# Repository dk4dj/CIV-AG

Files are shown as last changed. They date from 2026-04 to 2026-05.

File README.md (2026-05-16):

# WT32-ETH01 — CI-V → Antenna Genius Bridge

Arduino sketch for the **WT32-ETH01** (ESP32 + LAN8720). Reads Icom CI-V frequency and TX status, automatically switches a **4O3A Antenna Genius** antenna selector, and provides reliable TX inhibit for both the Icom transceiver and SmartSDR/FlexRadio via a two-layer interlock implementation. An optional **EA DOGL128W-6** display with rotary encoder provides on-device status, antenna selection, and system information.

---

## Features

- **Automatic AG discovery** — UDP broadcast on port 9007; extracts IP, port, serial, firmware, ports, antennas, mode, uptime
- **Full AG configuration readout** — band table and antenna list on every connect
- **CI-V frequency tracking** on UART2 — transceiver address learned automatically; active polling (Cmd 0x03) after `CIV_BROADCAST_TIMEOUT_MS` (1 s)
- **CI-V TX status** (Cmd 0x1C/0x00) polled every 200 ms — drives TX/RX indicator on display and web UI
- **Automatic band → antenna mapping** based on AG TX masks
- **Four-layer TX protection** — all controlled together via `setConflict()`:
  - GPIO4 HIGH → hardware PTT inhibit line
  - CI-V Cmd 0x16/0x66 → TX Inhibit on newer Icom transceivers
  - FlexRadio server `state=PTT_REQUESTED` → AG sets `inhibit=1` on Port B
  - SmartSDR Ethernet Interlock `not_ready` → SmartSDR TX blocked directly
- **Conflict reason display** — web UI and log show which transceiver was inhibited with address, frequency and antenna name
- **Correct conflict detection** — `wantedAntId` tracks the last requested antenna independently of AG status (AG sets `txant=0` when `inhibit=1`); re-evaluated on every Port B update
- **Source=AUTO guard** — ignores AG startup state for own port until first CI-V frame received
- **CI-V timeout** (`CIV_TIMEOUT_MS` = 5 s) — releases port and activates all inhibit mechanisms
- **FlexRadio two-layer implementation:**
  - **Server** (port 4992, up to `FLEX_MAX_CLIENTS` = 4): emulates a FlexRadio for the AG; sends `PTT_REQUESTED` proactively after `keepalive enable`
  - **Client**: connects to real FLEX radio; `interlock create type=ANT model=... valid_antennas=`; `not_ready`/`ready` with hex interlock ID
- **Separate UDP sockets** — `flexDiscUdp` (send-only) and `flexListenUdp` (receive-only on port 4992) to avoid ESP32 conflict
- **Automatic FLEX radio selection** — priority: AG Port 2 nickname → NVS default IP → single radio → user selection
- **Persistent default radio** — NVS (`Preferences`), survives reboot
- **Shared JSON builder** `buildStatusJson()` — identical data for SSE push and `/api` polling
- **Band-ID lookup** by `bands[i].id` (AG Band-IDs are 1-based; array is 0-based)
- **Splash screen** at boot (128×64 px, PROGMEM)
- **Display inversion** on any conflict or CI-V timeout (ST7565 hardware invert)
- **Built-in web interface** on port 80 with live SSE, FLEX selection panel, conflict detail
- **Log export** — `GET /log`, 300 timestamped entries
- **Non-blocking architecture** throughout
- **DHCP** — no network configuration required

---

## Hardware

### GPIO Assignment

| Signal | GPIO | Notes |
|---|---|---|
| ETH CLK input | 0 | `ETH_CLOCK_GPIO0_IN`, from LAN8720 crystal |
| ETH Power/Reset | 16 | LAN8720 nRST — try `-1` if boot shows reset timeout |
| ETH MDC | 23 | |
| ETH MDIO | 18 | |
| ETH RMII (fixed) | 19, 21, 22, 25, 26, 27 | Cannot be reassigned |
| CI-V RX (UART2) | 5 | 1 kΩ pull-up to 3.3 V recommended |
| CI-V TX (UART2) | 17 | Active polling + TX Inhibit frames |
| TX inhibit / conflict output | 4 | HIGH = any conflict or CI-V timeout active |
| Display SI (MOSI) | 15 | Software-SPI |
| Display SCK | 14 | Software-SPI |
| Display CS | 12 | Active low |
| Display A0 | 2 | Strapping pin — safe after boot |
| Display RST | 33 | Active low |
| Encoder A | 39 | Input-only, ISR CHANGE, ext. 10 kΩ pull-up **required** |
| Encoder B | 36 | Input-only, ISR CHANGE, ext. 10 kΩ pull-up **required** |
| Encoder button | 35 | Input-only, polled, ext. 10 kΩ pull-up **required** |

> GPIO 35/36/39 are input-only with no internal pull-ups. GPIO 36/39 lie in register `GPIO.in1.val` (not `GPIO.in`). The ISR reads both pins as `(GPIO.in1.val >> (PIN - 32)) & 1`.

---

## Display & Encoder

### Menu states

| State | How to enter | How to leave |
|---|---|---|
| `MENU_STATUS` | Default / timeout | Short press → `MENU_ANT_SELECT`; long press ≥1s → `MENU_INFO` |
| `MENU_INFO` | Long press ≥1s from Status | Any press → `MENU_STATUS` |
| `MENU_ANT_SELECT` | Short press from Status or rotate | Press → `MENU_CONFIRM`; timeout |
| `MENU_CONFIRM` | Press from Ant Select | Press (confirm) or timeout |
| `MENU_FLEX_SELECT` | Automatic when multiple FLEX radios found | Short press = select; long press ≥2s = select + set NVS default |

### Status screen layout
```
21.465 MHz              RX     ← TX/RX indicator (inverted block when TX)
Band: 15m
Ant:  Beam_OB11-3
AG: OK  Port A           ← bottom status bar
```

### Info screen (long press)
```
WT32: 192.168.1.202
AG:   192.168.1.221
FW:4.1.8 S/N:C7-F6-42
FLEX: 192.168.1.100
      (Flexi)
────────────────────
CI-V: 0x94   19200 Bd
[Taste]=zurück
```

### Encoder: full 4-state Gray-code decoding
Both channels (GPIO 39/36) trigger `CHANGE` interrupts. The ISR uses a 4-bit state machine — only valid Gray-code transitions count; glitches and crosstalk are filtered automatically. Adjust `ENC_PULSES_PER_DETENT` (default 4) if steps are missed or doubled.

---

## Web Interface

Open `http://<device-ip>/` in any browser.

| Section | Content |
|---|---|
| Funkgerät (CI-V) | Address, frequency, active band, TX/RX status |
| Antenna Genius | Name, IP, firmware, uptime, status |
| Port-Belegung | Port A/B antenna/band, **Funkgerät TX** (from Cmd 0x1C), conflict badge with inhibited TRX details, FlexRadio status |
| FLEX-Radio-Auswahl | Yellow warning card when multiple radios found |
| Band-/Antennen-Konfiguration | Full AG tables |
| Debug-Log | Live SSE log, 300 entries, download |

**Endpoints:** `GET /`, `GET /api`, `GET /events`, `GET /log`, `POST /flex-select?ip=`, `POST /flex-default?ip=`

---

## CI-V Protocol Details

| Command | Direction | Purpose |
|---|---|---|
| `FE FE <trx> E0 03 FD` | WT32 → TRX | Poll frequency |
| `FE FE <trx> E0 00 FD` | TRX → WT32 | Frequency broadcast |
| `FE FE E0 <trx> 00 ... FD` | TRX → WT32 | Frequency response |
| `FE FE <trx> E0 1C 00 FD` | WT32 → TRX | Poll TX status (every 200 ms) |
| `FE FE E0 <trx> 1C 00 00 FD` | TRX → WT32 | RX status |
| `FE FE E0 <trx> 1C 00 01 FD` | TRX → WT32 | TX status |
| `FE FE <trx> E0 16 66 01 FD` | WT32 → TRX | TX Inhibit ON |
| `FE FE <trx> E0 16 66 00 FD` | WT32 → TRX | TX Inhibit OFF |

---

## FlexRadio Interlock

### Server (AG interlock)
- VITA-49 discovery broadcast every 2 s + TCP server port 4992
- Sends `S00000000|interlock state=PTT_REQUESTED` immediately after `keepalive enable`
- Log prefix: `[FLEX:N]`

### Client (SmartSDR direct interlock)
```
→ C1|client program CIV-Bridge
→ C2|interlock create type=ANT model=CIV-Bridge serial=DK4DJ-1 valid_antennas=
← R2|0|000000F4          ← hex interlock ID
→ C3|interlock not_ready 000000F4   ← conflict
→ C4|interlock ready 000000F4       ← resolved
```
- Log prefix: `[FRINT]`
- FLEX radio IP from `ip=` field in VITA-49 payload (more reliable than UDP sender IP)
- Auto-select priority: AG Port 2 nickname → NVS default → single radio → user

---

## TX Inhibit Mechanisms

All controlled via `setConflict(bool active, const char *reason)`:

| Layer | Mechanism | Effect |
|---|---|---|
| GPIO4 HIGH | `digitalWrite` | Hardware PTT line to TRX |
| CI-V 0x16/0x66 | Serial2 frame | Icom TX Inhibit (newer models) |
| FlexRadio server | `PTT_REQUESTED` status | AG `inhibit=1` on Port B |
| FlexRadio client | `interlock not_ready` | SmartSDR TX blocked directly |

`conflictReason` is built with CI-V address, frequency and antenna name. Set before `wantedAntId = 0` so the last active antenna appears in the conflict message.

---

## Antenna Conflict Detection

### wantedAntId

The AG sets `txant=0` in status messages when `inhibit=1`. Without a separate tracking variable `portTxAnt[AG_RADIO_PORT-1]` would become 0, causing false "no conflict" decisions.

`wantedAntId` is set in `setAGPort()`, cleared in `releaseAGPort()`, and never overwritten by AG status updates. `checkAndSignalConflict()` uses it as fallback when called with argument 0.

### Antenna menu filtering (`menuBuildAntList`)

The selection menu excludes:
- `activeAnt` — already active on own port
- `blockedAnt = portTxAnt[otherIdx]` — currently used by SmartSDR

This prevents selecting an antenna that is already occupied on either port.

---

## Setup

### Arduino IDE

| Setting | Value |
|---|---|
| Board | ESP32 Dev Module |
| Flash Mode | QIO |
| Flash Size | 4 MB |
| ESP32 core | Espressif ESP32 Arduino ≥ 2.x |

### Libraries

| Library | When required |
|---|---|
| ETH, WiFiUdp, WiFiClient, WiFiServer, WebServer, Preferences | Always (ESP32 core) |
| U8g2 by olikraus | `DISPLAY_ENABLED 1` |

### Key Configuration Constants

```cpp
#define DISPLAY_ENABLED          1
#define FLEX_EMULATION_ENABLED   1
#define AG_RADIO_PORT            1      // 1=Port A, 2=Port B
#define ETH_POWER_PIN            16     // try -1 on some board revisions
#define CONFLICT_PIN             4
#define CIV_BAUD                 19200
#define CIV_BROADCAST_TIMEOUT_MS 1000   // active poll after 1 s without broadcast
#define CIV_TIMEOUT_MS           5000   // release port after 5 s without CI-V
#define FLEX_INTERLOCK_NAME      "CIV-Bridge"
#define FLEX_INTERLOCK_SERIAL    "DK4DJ-1"
#define FLEX_MAX_CLIENTS         4
#define FLEX_MAX_RADIOS          8
#define ENC_PULSES_PER_DETENT    4      // 4 for most encoders; try 2 or 1 if steps skip
#define DISP_CONTRAST            45
#define DEBUG_CONFLICT           0      // set to 1 for conflict diagnostic logging
#define LOG_BUF_LINES            300
```

---

## Troubleshooting

| Symptom | Likely cause | Fix |
|---|---|---|
| `TG1WDT_SYS_RESET` at boot | Wrong `ETH_POWER_PIN` | Try `ETH_POWER_PIN -1` |
| AG not found | UDP blocked | Check `[DISC]` in log |
| SmartSDR still transmits | FLEX radio not connected | Check `[FRINT]` entries in log |
| No `[FRINT]` entries | `flexListenUdp` not receiving | Verify port 4992 not blocked |
| Interlock ID −1 | `interlock create` rejected | Check `[FRINT] <<` responses |
| Conflict after band change | AG `txant=0` during inhibit | Handled by `wantedAntId` |
| Port A/B shows `---` | Port released after timeout | Normal — clears on next CI-V |
| Encoder skips steps | Wrong `ENC_PULSES_PER_DETENT` | Try values 1, 2, 4 |
| TX indicator wrong | TRX does not respond to Cmd 0x1C | Check CI-V Transceive setting |
| Conflict at startup | AG reports old session state | Handled by source=AUTO guard |

---

## License

GNU General Public License v3.0

*Developed with the assistance of [Claude.ai](https://claude.ai) by Anthropic.*

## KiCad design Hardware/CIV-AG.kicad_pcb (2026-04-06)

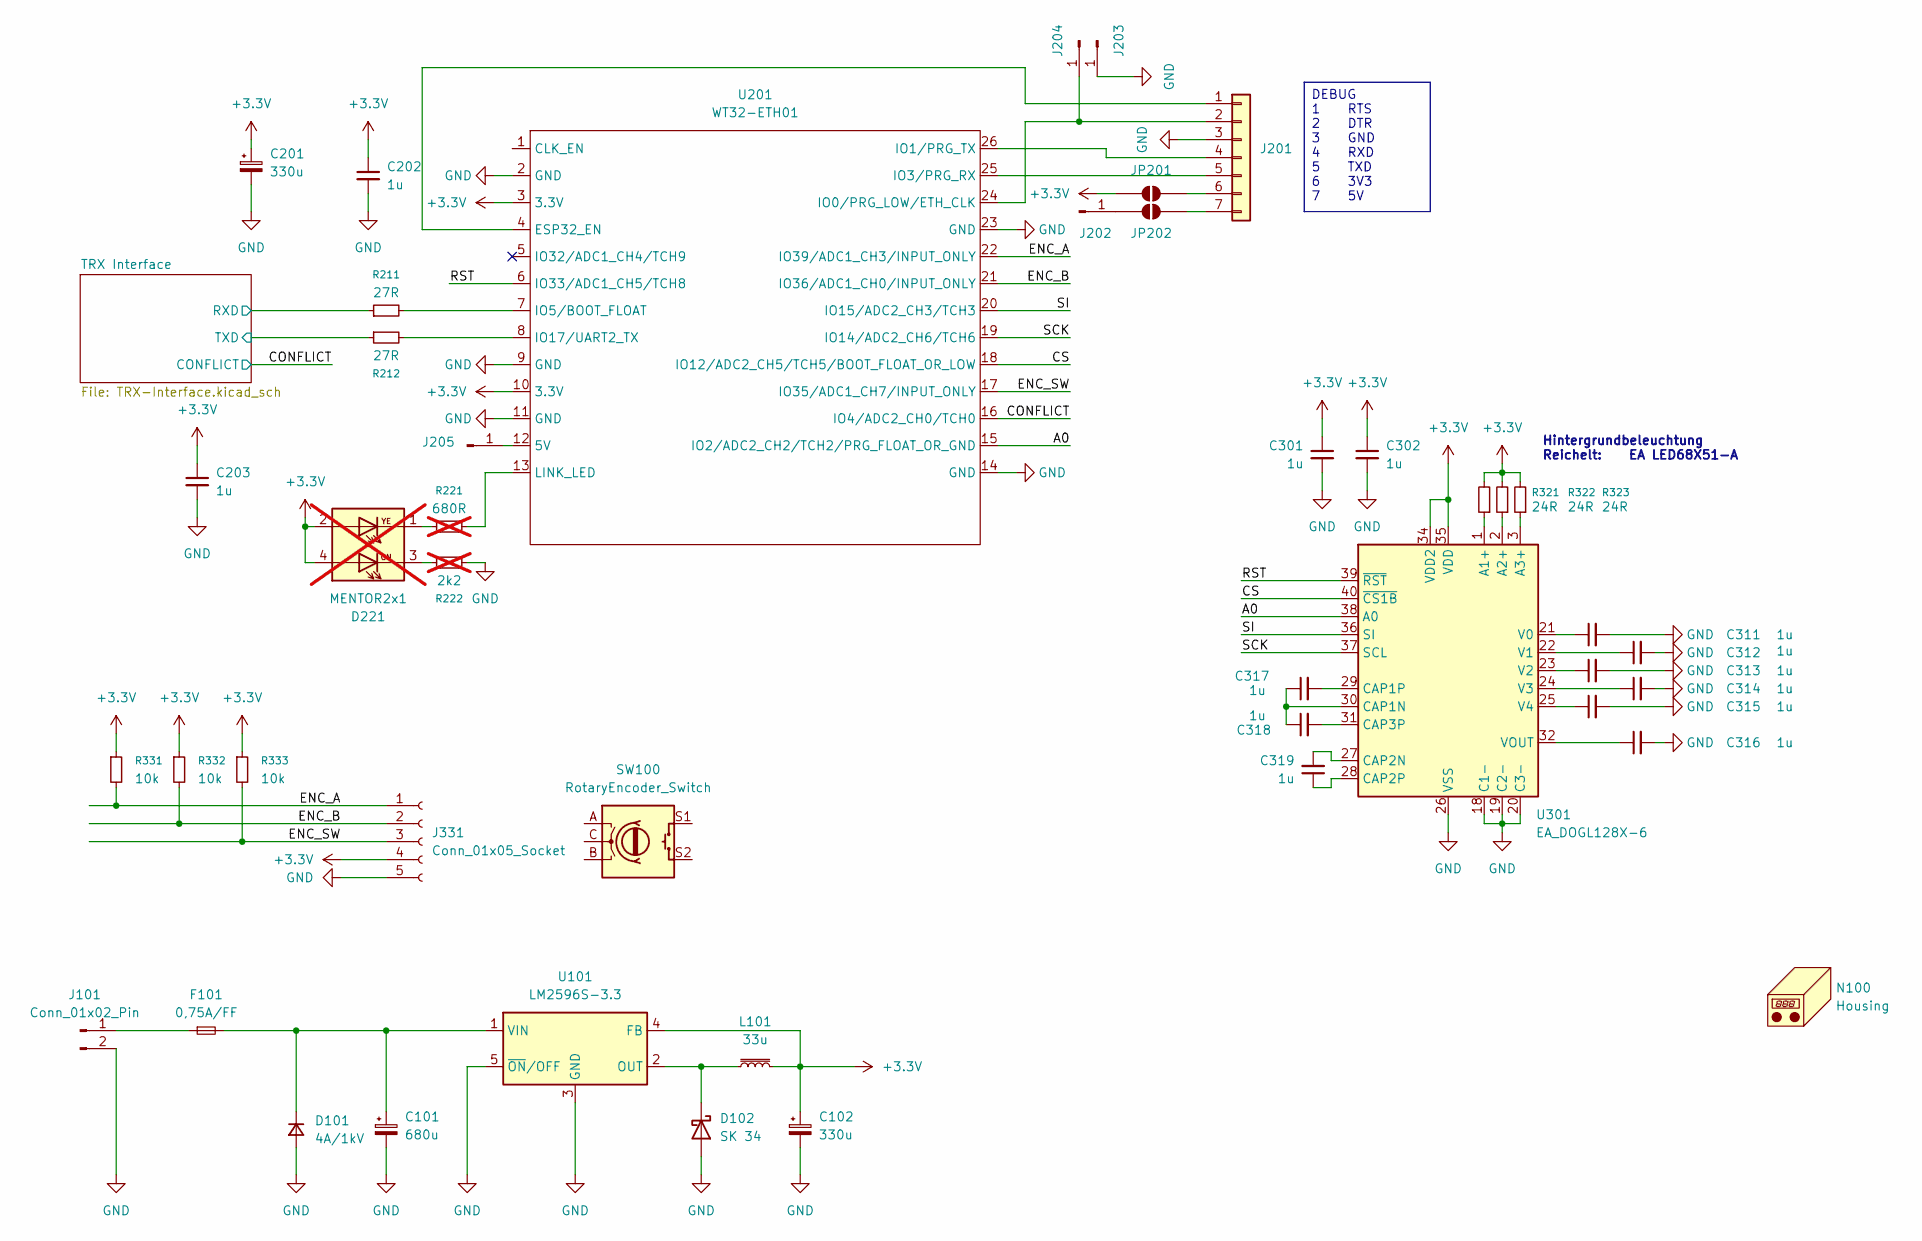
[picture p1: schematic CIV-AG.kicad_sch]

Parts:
C101: 680u; CP_Elec_10x10.5
C102, C201: 330u; CP_Elec_6.3x7.7
C202, C203, C301, C302, C311, C312, C313, C314, C315, C316, C317, C318, C319: 1u; C_0805_2012Metric_Pad1.18x1.45mm_HandSolder
D101: 4A/1kV; D_SMC_Handsoldering
D102: SK 34; D_SMA_Handsoldering
D221: MENTOR2x1; not fitted
F101: 0,75A/FF; Fuseholder_Littelfuse_Nano2_154x; DigiKey F1221CT-ND
J101: Conn_01x02_Pin; JST_EH_B2B-EH-A_1x02_P2.50mm_Vertical
J201: BL 15 SMD 043 7; PinSocket_1x07_P2.54mm_Vertical_SMD_Pin1Left; DigiKey 5496-BL15SMD0437-ND
J202, J203, J204, J205: Conn_01x01_Pin; SolderWirePad_1x01_SMD_2x4mm
J331: Conn_01x05_Socket; PinSocket_1x05_P2.54mm_Vertical
JP201, JP202: SolderJumper_2_Open; SolderJumper-2_P1.3mm_Open_RoundedPad1.0x1.5mm
L101: 33u; L_Fastron_PISR_Handsoldering
N100: Housing; DigiKey HM1719-ND
R211, R212: 27R; R_0805_2012Metric_Pad1.20x1.40mm_HandSolder
R221: 680R; R_0805_2012Metric_Pad1.20x1.40mm_HandSolder; not fitted
R222: 2k2; R_0805_2012Metric_Pad1.20x1.40mm_HandSolder; not fitted
R321, R322, R323: 24R; R_0805_2012Metric_Pad1.20x1.40mm_HandSolder
R331, R332, R333: 10k; R_0805_2012Metric_Pad1.20x1.40mm_HandSolder
SW100: RotaryEncoder_Switch
U101: LM2596S-3.3; TO-263-5_TabPin3; DigiKey LM2596S-3.3/NOPB-ND
U201: WT32-ETH01; WT32-ETH01_SMD; DigiKey 1597-102991455-ND
U301: EA_DOGL128X-6; EA_DOGL128-6; DigiKey 1481-1058-ND

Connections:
+3.3V: C102.1, C201.1, C202.1, C203.1, C301.1, C302.1, D221.2 (KB), D221.4 (KR), J331.4, JP201.1 (A), L101.2, R321.2, R322.2, R323.2, R331.1, R332.1, R333.1, U101.4 (FB), U201.3 (3.3V), U201.10 (3.3V), U301.34 (VDD2), U301.35 (VDD); also elsewhere on the board
/A0: U201.15 (IO2/ADC2_CH2/TCH2/PRG_FLOAT_OR_GND), U301.38 (A0)
/CONFLICT: U201.16 (IO4/ADC2_CH0/TCH0); also elsewhere on the board
/CS: U201.18 (IO12/ADC2_CH5/TCH5/BOOT_FLOAT_OR_LOW), U301.40 (~CS1B)
/ENC_A: J331.1, R331.2, U201.22 (IO39/ADC1_CH3/INPUT_ONLY)
/ENC_B: J331.2, R332.2, U201.21 (IO36/ADC1_CH0/INPUT_ONLY)
/ENC_SW: J331.3, R333.2, U201.17 (IO35/ADC1_CH7/INPUT_ONLY)
/RST: U201.6 (IO33/ADC1_CH5/TCH8), U301.39 (~RST)
/SCK: U201.19 (IO14/ADC2_CH6/TCH6), U301.37 (SCL)
/SI: U201.20 (IO15/ADC2_CH3/TCH3), U301.36 (SI)
/TRX Interface/RXD: R211.1; also elsewhere on the board
/TRX Interface/TXD: R212.1; also elsewhere on the board
GND: C101.2, C102.2, C201.2, C202.2, C203.2, C301.2, C302.2, C311.2, C312.2, C313.2, C314.2, C315.2, C316.2, D101.2 (A), D102.2 (A), J101.2, J201.3, J203.1 (Pin_1_1), J331.5, R222.2, U101.3 (GND), U101.5 (~ON/OFF), U201.2 (GND), U201.9 (GND), U201.11 (GND), U201.14 (GND), U201.23 (GND), U301.18 (C1-), U301.19 (C2-), U301.20 (C3-), U301.26 (VSS), U301.33 (VSS); also elsewhere on the board
unnamed: C101.1, D101.1 (K), F101.2, U101.1 (VIN)
unnamed: D102.1 (K), L101.1, U101.2 (OUT)
unnamed: D221.1 (AB), R221.1
unnamed: D221.3 (AR), R222.1
unnamed: F101.1, J101.1
unnamed: J201.1, U201.4 (ESP32_EN)
unnamed: J201.2, J204.1 (Pin_1_1), U201.24 (IO0/PRG_LOW/ETH_CLK)
unnamed: J201.4, U201.26 (IO1/PRG_TX)
unnamed: J201.5, U201.25 (IO3/PRG_RX)
unnamed: J201.6, JP201.2 (B)
unnamed: J201.7, JP202.2 (B)
unnamed: J202.1 (Pin_1_1), JP202.1 (A)
unnamed: J205.1 (Pin_1_1), U201.12 (5V)
unnamed: R211.2, U201.7 (IO5/BOOT_FLOAT)
unnamed: R212.2, U201.8 (IO17/UART2_TX)
unnamed: R221.2, U201.13 (LINK_LED)
unnamed: R321.1, U301.1 (A1+)
unnamed: R322.1, U301.2 (A2+)
unnamed: R323.1, U301.3 (A3+)
unnamed: C317.1, C318.1, U301.30 (CAP1N)
unnamed: C317.2, U301.29 (CAP1P)
unnamed: C319.2, U301.27 (CAP2N)
unnamed: C319.1, U301.28 (CAP2P)
unnamed: C318.2, U301.31 (CAP3P)
unnamed: C311.1, U301.21 (V0)
unnamed: C312.1, U301.22 (V1)
unnamed: C313.1, U301.23 (V2)
unnamed: C314.1, U301.24 (V3)
unnamed: C315.1, U301.25 (V4)
unnamed: C316.1, U301.32 (VOUT)

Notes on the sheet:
Hintergrundbeleuchtung Reichelt: EA LED68X51-A
DEBUG 1 RTS 2 DTR 3 GND 4 RXD 5 TXD 6 3V3 7 5V

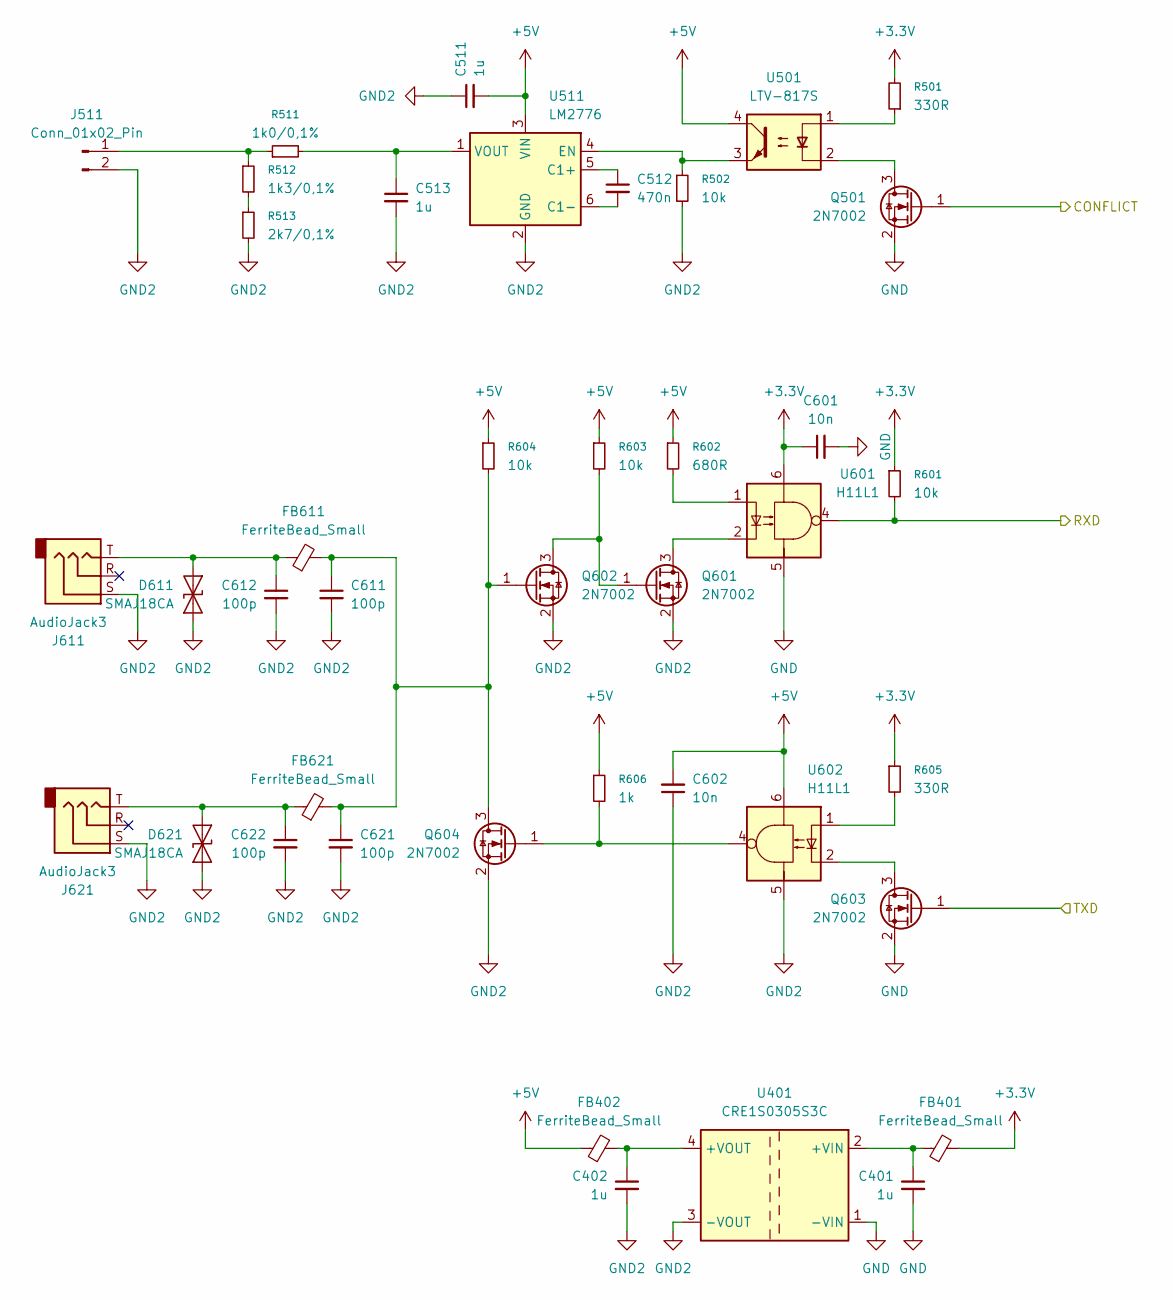
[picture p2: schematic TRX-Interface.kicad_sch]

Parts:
C401, C402, C511, C513: 1u; C_0805_2012Metric_Pad1.18x1.45mm_HandSolder
C512: 470n; C_0805_2012Metric_Pad1.18x1.45mm_HandSolder
C601, C602: 10n; C_0805_2012Metric_Pad1.18x1.45mm_HandSolder
C611, C612, C621, C622: 100p; C_0805_2012Metric_Pad1.18x1.45mm_HandSolder
D611, D621: SMAJ18CA; D_SMA
FB401, FB402, FB611, FB621: FerriteBead_Small; L_0805_2012Metric_Pad1.05x1.20mm_HandSolder; DigiKey 732-1606-1-ND
J511: Conn_01x02_Pin; JST_EH_B2B-EH-A_1x02_P2.50mm_Vertical
J611, J621: AudioJack3; Jack_3.5mm_Lumberg_1503_07_Horizontal
Q501, Q601, Q602, Q603, Q604: 2N7002; SOT-23
R501, R605: 330R; R_0805_2012Metric_Pad1.20x1.40mm_HandSolder
R502, R601, R603, R604: 10k; R_0805_2012Metric_Pad1.20x1.40mm_HandSolder
R511: 1k0/0,1%; R_0805_2012Metric_Pad1.20x1.40mm_HandSolder
R512: 1k3/0,1%; R_0805_2012Metric_Pad1.20x1.40mm_HandSolder
R513: 2k7/0,1%; R_0805_2012Metric_Pad1.20x1.40mm_HandSolder
R602: 680R; R_0805_2012Metric_Pad1.20x1.40mm_HandSolder
R606: 1k; R_0805_2012Metric_Pad1.20x1.40mm_HandSolder
U401: CRE1S0305S3C; Converter_DCDC_Murata_CRE1xxxxxx3C_THT; DigiKey 811-3193-ND
U501: LTV-817S; SMDIP-4_W9.53mm
U511: LM2776; SOT-23-6; DigiKey 296-43957-1-ND
U601, U602: H11L1; DIP-6_W8.89mm_SMDSocket_LongPads; DigiKey H11L1SR2MCT-ND

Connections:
+3.3V: C601.1, FB401.2, R501.2, R601.1, R605.1, U601.6; also elsewhere on the board
+5V: C511.2, C602.2, FB402.1, R602.1, R603.1, R604.1, R606.1, U501.4, U511.3 (VIN), U602.6
/CONFLICT: Q501.1 (G); also elsewhere on the board
/TRX Interface/RXD: R601.2, U601.4; also elsewhere on the board
/TRX Interface/TXD: Q603.1 (G); also elsewhere on the board
GND: C401.2, C601.2, Q501.2 (S), Q603.2 (S), U401.1 (-VIN), U601.5; also elsewhere on the board
GND2: C402.2, C511.1, C513.2, C602.1, C611.2, C612.2, C621.2, C622.2, D611.1 (A1), D621.1 (A1), J511.2, J611.S, J621.S, Q601.2 (S), Q602.2 (S), Q604.2 (S), R502.2, R513.2, U401.3 (-VOUT), U511.2 (GND), U602.5
unnamed: C612.1, D611.2 (A2), FB611.1, J611.T
unnamed: C622.1, D621.2 (A2), FB621.1, J621.T
unnamed: J511.1, R511.1, R512.1
unnamed: Q501.3 (D), U501.2
unnamed: Q601.3 (D), U601.2
unnamed: Q601.1 (G), Q602.3 (D), R603.2
unnamed: C611.1, C621.1, FB611.2, FB621.2, Q602.1 (G), Q604.3 (D), R604.2
unnamed: Q603.3 (D), U602.2
unnamed: Q604.1 (G), R606.2, U602.4
unnamed: R501.1, U501.1
unnamed: R512.2, R513.1
unnamed: R602.2, U601.1
unnamed: R605.2, U602.1
unnamed: C401.1, FB401.1, U401.2 (+VIN)
unnamed: C402.1, FB402.2, U401.4 (+VOUT)
unnamed: C512.1, U511.5 (C1+)
unnamed: C512.2, U511.6 (C1-)
unnamed: R502.1, U501.3, U511.4 (EN)
unnamed: C513.1, R511.2, U511.1 (VOUT)

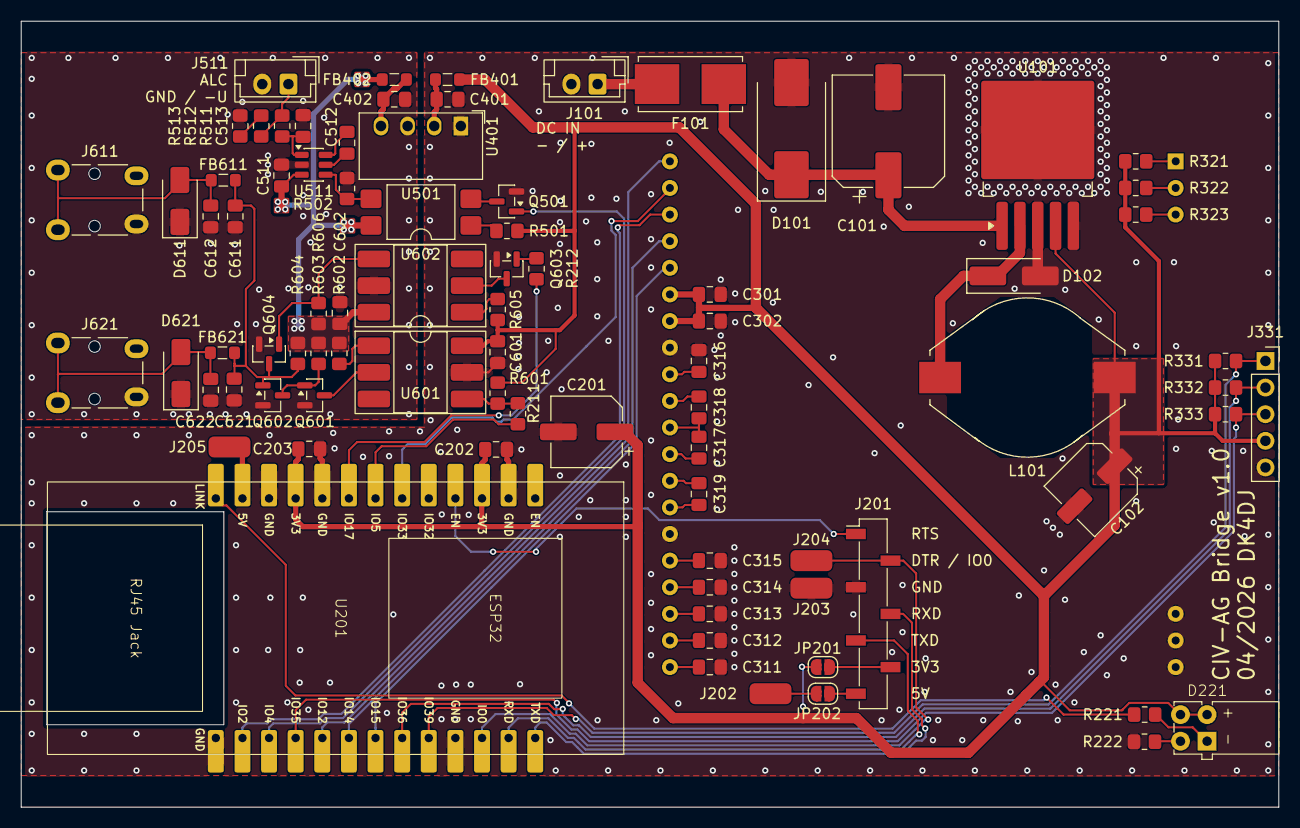
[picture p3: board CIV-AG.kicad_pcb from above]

Board: 2 copper layers, 120.0 x 75.0 mm, 84 parts (1 on the bottom side), 64 nets.

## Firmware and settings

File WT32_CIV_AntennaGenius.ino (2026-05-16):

/*
 * WT32-ETH01 — CI-V Bus → Antenna Genius Bridge
 * ================================================
 * Hardware : WT32-ETH01 (ESP32 + LAN8720)
 * CI-V Bus : UART2  (GPIO5 = RX2, GPIO17 = TX2)
 *            Open-Collector → 1 kΩ Pull-up auf 3.3 V empfohlen.
 *
 * Ethernet : DHCP, AG-Discovery via UDP-Broadcast Port 9007
 * AG API   : TCP Port 9007 (ASCII-Protokoll)
 *
 * Display  : EA DOGL128W-6 (ST7565, 128×64, Software-SPI)
 *            Bibliothek: U8g2 by olikraus (Arduino Library Manager)
 *            SI=GPIO15  SCK=GPIO14  CS=GPIO12  A0=GPIO2  RST=GPIO33
 *
 * Encoder  : Drehencoder mit Taster
 *            A=GPIO39  B=GPIO36  BTN=GPIO35
 *            Alle input-only → externe 10 kΩ Pull-ups an 3.3 V zwingend!
 *            GPIO36/39 teilen 270 pF interne Kapazität → B per Polling
 *            gelesen (kein ISR) um Crosstalk zu vermeiden.
 *
 * FlexRadio: Zwei-Ebenen-Implementierung:
 *   Server: VITA-49 Discovery-Emulation (UDP/TCP Port 4992)
 *           AG erkennt CI-V-Port als FlexRadio → setzt tx=1 bei aktivem TRX
 *           Bis zu FLEX_MAX_CLIENTS (4) gleichzeitige TCP-Clients
 *           Status proaktiv nach keepalive enable gesendet (kein sub tx nötig)
 *   Client: WT32 verbindet sich direkt zum echten FLEX-Radio auf Port 4992
 *           Registriert ANT-Interlock → SmartSDR TX-Inhibit bei Konflikt
 *           FLEX-Radio-IP aus VITA-49 Discovery (flexListenUdp, Port 4992)
 *           Persistente Radio-Auswahl via NVS (Preferences)
 *
 * Ablauf:
 *  1. Ethernet per DHCP initialisieren
 *  2. AG per UDP-Broadcast suchen → IP + Port aus Discovery-Paket
 *  3. TCP-Verbindung zum AG (Port aus Discovery, Fallback 9007)
 *  4. sub port all → Port-Statusänderungen abonnieren
 *  5. band list + antenna list → Konfiguration einlesen
 *  6. CI-V-Frequenz empfangen oder aktiv pollen (Cmd 0x03)
 *     → nach CIV_BROADCAST_TIMEOUT_MS (1 s) ohne Broadcast aktiv pollen
 *     → Band bestimmen → port set senden
 *  7. CI-V-Timeout (CIV_TIMEOUT_MS = 5 s): Port freigeben, alle Sperren aktiv
 *  8. FlexRadio-Server: Discovery-Broadcast alle 2 s,
 *     TCP-Server sendet Interlock-Status proaktiv nach keepalive enable
 *  9. FlexRadio-Client: entdeckt FLEX-Radios via VITA-49 UDP-Broadcast,
 *     wählt automatisch das AG-verbundene Radio, registriert ANT-Interlock
 * 10. TX-Status (Cmd 0x1C/0x00) alle 200 ms abfragen → civTransmitting,
 *     portTx[], Web-UI Badge und Display TX/RX-Indikator
 *
 * Sicherheitsfunktionen (alle über setConflict() synchron):
 *  - GPIO4 HIGH:        TX-Inhibit-Hardwareleitung zum TRX
 *  - CI-V Cmd 16/66:   TX-Inhibit über CI-V (neuere Icom-TRX)
 *  - FlexRadio Server:  state=PTT_REQUESTED → AG sperrt Port B
 *  - FlexRadio Client:  interlock not_ready → SmartSDR TX-Inhibit direkt
 *  setConflict() befüllt conflictReason (Anzeige im Web-UI)
 *
 * Display-Menüstruktur:
 *  MENU_STATUS     Normalanzeige (Frequenz, Band, Antenne, TX/RX)
 *  MENU_INFO       Info-Seite: IP, CI-V, AG, FLEX (langer Tastendruck ≥1s)
 *  MENU_ANT_SELECT Antennen-Auswahl (kurzer Tastendruck; zeigt nur freie Ant.)
 *  MENU_CONFIRM    Bestätigungsdialog
 *  MENU_FLEX_SELECT FLEX-Radio Auswahl (erscheint automatisch)
 *
 * Konflikt-Erkennung:
 *  wantedAntId merkt sich die zuletzt angeforderte Antenne unabhängig vom
 *  AG-Status (AG setzt txant=0 bei inhibit=1). checkAndSignalConflict(0)
 *  verwendet wantedAntId als Fallback wenn portTxAnt[AG_RADIO_PORT-1]=0.
 *  parsePortLine() löst Re-Check bei jedem Update des anderen Ports aus.
 *
 * AG-Protokoll-Hinweise:
 *  - Kommando-Terminator: \r\n (nicht nur \r)
 *  - write() + flush() verwenden, NICHT print()
 *  - Antwortblock endet mit R<seq>|0| (leere Message = Blockende)
 *  - sendAGCfgCmd() setzt agCfgSeq + agCfgTimeout immer zusammen
 *  - sub port all: Parameter "all" ist Pflicht; sub antenna existiert nicht
 *  - AG sendet kein sub tx — Status proaktiv nach keepalive enable senden
 *
 * SmartSDR Ethernet-Interlock:
 *  - type=ANT Interlock via "interlock create type=ANT model=... serial=..."
 *  - Sperren:    "interlock not_ready <id>"
 *  - Freigeben:  "interlock ready <id>"
 *  - IP-Discovery: flexListenUdp (Port 4992, getrennt von flexDiscUdp)
 *  - Radio-Auswahl: auto via AG-Port-Nickname, NVS-Default oder manuell
 *
 * Web-Interface:
 *  - buildStatusJson() als gemeinsame Funktion für SSE und /api
 *  - conflictReason zeigt gesperrten TRX mit Adresse, Frequenz und Antenne
 *  - bandA/bandB: Suche nach bands[i].id == portBand[x] (AG-Band-ID, 1-basiert)
 *
 * Konfigurierbare Parameter (alle als #define):
 *  DISPLAY_ENABLED        1/0   Display + Encoder aktivieren
 *  FLEX_EMULATION_ENABLED 1/0   FlexRadio-Emulation aktivieren
 *  CIV_BAUD               19200 Baudrate CI-V
 *  CIV_BROADCAST_TIMEOUT_MS 1000 Nach 1 s ohne Broadcast aktiv pollen
 *  DEBUG_CONFLICT          0/1   TX-Konflikt-Debugging aktivieren
 *  CIV_TIMEOUT_MS         5000  Inaktivitäts-Timeout TRX → Port freigeben
 *  AG_RADIO_PORT          1     Genutzter AG-Port (1=A, 2=B)
 *  ETH_POWER_PIN          16    LAN8720 Reset (-1 auf manchen Boards)
 *  FLEX_MODEL/SERIAL      ...   Gerätekennzeichnung in AG-flex-list
 *  FLEX_INTERLOCK_NAME    ...   ANT-Interlock-Name in SmartSDR
 *  FLEX_INTERLOCK_SERIAL  ...   Seriennummer des Interlocks
 *  FLEX_MAX_RADIOS        8     Max. gespeicherte FLEX-Radios
 *  DISP_CONTRAST          45    Display-Kontrast 0-63
 *
 * Bibliotheken (Board: esp32 by Espressif ≥ 2.x):
 *  - ETH.h, WiFiUdp.h, WiFiClient.h, WiFiServer.h,
 *    WebServer.h, Preferences.h  (alle im ESP32-Arduino-Core enthalten)
 *  - U8g2lib.h   (nur wenn DISPLAY_ENABLED 1)
 *
 * Board-Einstellungen Arduino IDE:
 *  Board: ESP32 Dev Module  |  Flash: QIO 4MB
 */
#include <ETH.h>
#include <WiFiUdp.h>
#include <WiFiClient.h>
#include <WiFiServer.h>
#include <WebServer.h>
#include <Preferences.h>   // NVS für persistente FLEX-Radio-Auswahl

// ─── Display & Encoder aktivieren ───────────────────────────────────────────
// Auf 0 setzen um Display und Encoder vollständig zu deaktivieren
// (kein #include, keine Pin-Belegung, kein Code-Overhead)
#define DISPLAY_ENABLED  1

#if DISPLAY_ENABLED
#include <U8g2lib.h>
#include <SPI.h>
#endif

// ─── WT32-ETH01 Ethernet-Pins ───────────────────────────────────────────────
#define ETH_CLK_MODE    ETH_CLOCK_GPIO0_IN
#define ETH_POWER_PIN   16
#define ETH_TYPE        ETH_PHY_LAN8720
#define ETH_ADDR        1
#define ETH_MDC_PIN     23
#define ETH_MDIO_PIN    18

// ─── CI-V UART ──────────────────────────────────────────────────────────────
#define CIV_BAUD        19200
#define CIV_RX_PIN      5
#define CIV_TX_PIN      17
#define CIV_POLL_MS     500     // Frequenz aktiv abfragen wenn kein Broadcast
#define CIV_BROADCAST_TIMEOUT_MS 1000  // nach 1 s ohne Broadcast → aktiv pollen
#define CIV_TIMEOUT_MS  5000    // nach 5 s ohne CI-V → TRX abgeschaltet → Port freigeben

// ─── Antenna Genius ─────────────────────────────────────────────────────────
#define AG_PORT         9007
#define AG_KEEPALIVE_MS 5000
#define AG_RECONNECT_MS 15000
#define AG_CFG_TIMEOUT_MS 8000  // max. Wartezeit pro Config-Schritt
#define PORT_POLL_MS    3000    // Port-Status aktiv abfragen alle N ms
#define MAX_BANDS       16
#define MAX_ANTENNAS    16
#define AG_RADIO_PORT   1       // Radio-Port A = 1

// ─── Konflikt-Ausgang ────────────────────────────────────────────────────────
#define CONFLICT_PIN    4
#define DEBUG_CONFLICT  0   // 1 = checkAndSignalConflict logt jeden Check (Debugging)

// ─── Display (EA DOGL128W-6, ST7565, Software-SPI) ──────────────────────────
// Alle Pins sind am WT32-ETH01 frei verfügbar.
// GPIO2  : Vorsicht beim Flashen (Strapping-Pin) – nach dem Flash normal nutzbar.
// GPIO35/36: Input-Only – daher ideal für Encoder-Eingänge (kein Output nötig).
#define DISP_MOSI_PIN   15   // SI  des DOGL128
#define DISP_SCK_PIN    14   // SCL des DOGL128
#define DISP_CS_PIN     12   // CSB des DOGL128 (active low)
#define DISP_A0_PIN      2   // A0  des DOGL128 (RS: 0=Cmd, 1=Data)
#define DISP_RST_PIN    33   // RST des DOGL128 (active low)

// ─── Drehencoder ─────────────────────────────────────────────────────────────
#define ENC_A_PIN       39   // Encoder Kanal A  (input-only, ext. Pull-up, ISR)
#define ENC_B_PIN       36   // Encoder Kanal B  (input-only, ext. Pull-up)
#define ENC_BTN_PIN     35   // Encoder Taster   (input-only, ext. Pull-up)
// Hinweis: GPIO35/36/39 sind input-only ohne internen Pull-up.
// Externe Pull-up-Widerstände (10 kΩ) an 3.3 V sind zwingend erforderlich!
// GPIO36/39 haben 270 pF interne Kapazität.
// Beide Kanaele werden per ISR ausgewertet (CHANGE auf A und B).
// Vollstaendiges 4-Zustand-Gray-Code-Decoding verhindert Fehlzaehlungen.
#define ENC_DEBOUNCE_MS  5   // Entprellzeit Taster in ms
#define ENC_PULSES_PER_DETENT 4  // Impulse pro Rastschritt (typisch 4; bei Fehlzaehlung 2 oder 1 versuchen)
#define MENU_TIMEOUT_MS 10000 // Menü schließt sich nach 10 s Inaktivität

// ─── Web-Server ──────────────────────────────────────────────────────────────
#define WEB_PORT        80
#define LOG_BUF_LINES   300      // Ringpuffer für Web-Log (inkl. Zeitstempel)

// ─── FlexRadio-Emulation (PTT-Interlock für Antenna Genius) ─────────────────
// Emuliert das FlexRadio VITA-49-Discovery-Protokoll damit der AG unseren
// CI-V-Port als "FLEX"-Radio erkennt und tx=1 setzt wenn der TRX aktiv ist.
// Der AG nutzt dies für die Konfliktverhinderung mit SmartSDR an Port B.
// Auf 0 setzen um die Emulation zu deaktivieren.
#define FLEX_EMULATION_ENABLED  1

#define FLEX_TCP_PORT      4992   // FlexRadio API-Port
#define FLEX_UDP_PORT      4992   // Discovery-Broadcast-Port
#define FLEX_DISCOVERY_MS  2000   // Discovery-Broadcast-Intervall
// Geräte-Identifikation die der AG in seiner flex list anzeigt
#define FLEX_MODEL         "FLEX-6300"
#define FLEX_SERIAL        "CIV-Bridge-1"
#define FLEX_NICKNAME      "CIV-Bridge"
#define FLEX_VERSION       "3.3.15"

// ─── SmartSDR Ethernet-Interlock (Client zum echten FLEX-Radio) ──────────────
// Der WT32 verbindet sich als Client direkt zum FLEX-Radio auf Port 4992
// und registriert dort einen ANT-Typ-Interlock.
// Damit sperrt SmartSDR TX zuverlässig bei Antennenkonflikt.
// IP des FLEX-Radios wird automatisch aus dem UDP-Discovery-Broadcast gelernt.
// Fallback-IP wenn Discovery noch nicht empfangen wurde (0.0.0.0 = kein Fallback):
#define FLEX_RADIO_PORT    4992
#define FLEX_INTERLOCK_NAME   "CIV-Bridge"
#define FLEX_INTERLOCK_SERIAL "DK4DJ-1"
#define FLEX_RADIO_RECONNECT_MS 20000  // Wiederverbindungsversuch alle 20 s
#define FLEX_MAX_RADIOS    8           // max. gleichzeitig gespeicherte FLEX-Radios
#define FLEX_MAX_CLIENTS   4           // max. gleichzeitige TCP-Clients am FlexRadio-Server

// ─── CI-V Konstanten ────────────────────────────────────────────────────────
#define CIV_PREAMBLE    0xFE
#define CIV_EOM         0xFD
#define CIV_CONTROLLER  0xE0
#define CIV_BUF_SIZE    32

// ═══════════════════════════════════════════════════════════════════════════
//  Datenstrukturen
// ═══════════════════════════════════════════════════════════════════════════

struct BandEntry {
  uint8_t  id;
  char     name[16];
  double   freqStart;
  double   freqStop;
  bool     valid;
};

struct AntennaEntry {
  uint8_t  id;
  char     name[32];
  uint16_t txMask;
  uint16_t rxMask;
  bool     valid;
};

// AG-Konfigurations-Einlese-Zustand (nicht-blockierend)
enum AgConfigState {
  AGCFG_IDLE,
  AGCFG_WAIT_SUB_PORT,      // warte auf Antwort von "sub port all"
  AGCFG_WAIT_BAND_LIST,     // warte auf Antwort von "band list"
  AGCFG_WAIT_ANTENNA_LIST,  // warte auf Antwort von "antenna list"
  AGCFG_DONE
};

// ═══════════════════════════════════════════════════════════════════════════
//  Globale Variablen
// ═══════════════════════════════════════════════════════════════════════════

static bool ethConnected = false;

WiFiUDP    udp;
WiFiClient agClient;

static IPAddress agIP;
static bool      agFound      = false;
static bool      agConnected  = false;
static bool      agConfigDone = false;
static uint32_t  agLastConnect = 0;

// AG Konfiguration
BandEntry    bands[MAX_BANDS];
uint8_t      bandCount    = 0;
AntennaEntry antennas[MAX_ANTENNAS];
uint8_t      antennaCount = 0;

// AG nicht-blockierender Config-State
static AgConfigState agCfgState   = AGCFG_IDLE;
static uint8_t       agCfgSeq     = 0;
static uint32_t      agCfgTimeout = 0;  // 0 = inaktiv; >0 = Ablaufzeitpunkt in ms

// Verzögerter Config-Start nach AG-Prologue (nicht-blockierend, ersetzt delay(200))
static uint32_t agConfigStartAt = 0;  // 0 = kein Start ausstehend; >0 = Startzeitpunkt

// Sequenznummer für AG-Kommandos (1–255, rollt über)
static uint8_t  agSeq    = 1;
static uint32_t lastPing = 0;

// AG Zeilen-Empfangspuffer (nicht-blockierend)
static String   agLineBuf;

// Gesammelte Antwortzeilen für laufendes Konfigurations-Kommando

// Port-Status
static uint8_t  portTxAnt[2]   = {0, 0};
static uint8_t  portRxAnt[2]   = {0, 0};
static uint8_t  portBand[2]    = {0, 0};
static bool     portTx[2]      = {false, false};
static uint8_t  wantedAntId    = 0;   // zuletzt angeforderte Antenne für AG_RADIO_PORT
                                       // bleibt gültig auch wenn AG txant=0 bei inhibit meldet
static bool     conflictActive = false;
static char     conflictReason[64] = ""; // Beschreibung des aktiven Konflikts für Web-UI
static uint32_t lastPortPoll   = 0;
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
void loop() {
  if (ethConnected) {
    webServer.handleClient();
    handleSSEClient();
#if FLEX_EMULATION_ENABLED
    flexLoop();
#endif
  }
  if (!ethConnected) return;

  if (!agFound)     { discoverAntennaGenius(); return; }
  if (!agConnected) { connectToAG();           return; }

  handleAGReceive();   // nicht-blockierend AG-Daten lesen & verarbeiten

#if DISPLAY_ENABLED
  // Encoder auch während Config-Phase auswerten (Menü immer bedienbar)
  menuHandleEncoder();
#endif

  if (!agConfigDone) return;

  handleCIV();
  sendKeepalive();
  pollPortStatus();

#if DISPLAY_ENABLED
  displayLoop();
#endif
}

// ═══════════════════════════════════════════════════════════════════════════
//  AG Discovery (UDP Broadcast)
// ═══════════════════════════════════════════════════════════════════════════

void discoverAntennaGenius() {
  static bool udpOpen = false;
  if (!udpOpen) {
    udp.begin(AG_PORT);
    udpOpen = true;
    snprintf(agStatusStr, sizeof(agStatusStr), "Suche...");
    webLog("[DISC] Warte auf AG Broadcast...");
  }

  int pktSize = udp.parsePacket();
  if (pktSize <= 0) return;

  char buf[256];
  int len = udp.read(buf, sizeof(buf) - 1);
  buf[len] = '\0';
  if (strncmp(buf, "AG ", 3) != 0) return;

  webLog("[DISC] Broadcast: %s", buf);

  // ip=
  char *ipStr = strstr(buf, "ip=");
  if (ipStr) {
    uint8_t a, b, c, d;
    if (sscanf(ipStr + 3, "%hhu.%hhu.%hhu.%hhu", &a, &b, &c, &d) == 4)
      agIP = IPAddress(a, b, c, d);
    else
      agIP = udp.remoteIP();
  } else {
    agIP = udp.remoteIP();
  }
  snprintf(agIPStr, sizeof(agIPStr), "%s", agIP.toString().c_str());

  // port=
  char *pp = strstr(buf, " port=");
  if (pp) sscanf(pp + 6, "%hu", &agTcpPort);

  // v= (Firmware — im Broadcast-Paket, wird ggf. durch Prologue überschrieben)
  char *vp = strstr(buf, " v=");
  if (vp) { char tmp[16]={0}; sscanf(vp + 3, "%15s", tmp); snprintf(agFwStr,  sizeof(agFwStr),  "%s", tmp); }

  // serial=
  char *sp = strstr(buf, "serial=");
  if (sp) { char tmp[24]={0}; sscanf(sp + 7, "%23s", tmp); snprintf(agSerialStr, sizeof(agSerialStr), "%s", tmp); }

  // name=
  char *np = strstr(buf, "name=");
  if (np) { char tmp[48]={0}; sscanf(np + 5, "%47s", tmp); snprintf(agNameStr, sizeof(agNameStr), "%s", tmp); }

  // ports=
  char *prp = strstr(buf, "ports=");
  if (prp) sscanf(prp + 6, "%hhu", &agPorts);

  // antennas=
  char *anp = strstr(buf, "antennas=");
  if (anp) sscanf(anp + 9, "%hhu", &agAntennas);

  // mode=
  char *mp = strstr(buf, "mode=");
  if (mp) { char tmp[12]={0}; sscanf(mp + 5, "%11s", tmp); snprintf(agModeStr, sizeof(agModeStr), "%s", tmp); }

  // uptime=
  char *up = strstr(buf, "uptime=");
  if (up) sscanf(up + 7, "%lu", &agUptime);

  webLog("[DISC] AG gefunden: %s  Name: %s  S/N: %s  FW: %s",
         agIPStr, agNameStr, agSerialStr, agFwStr);
  webLog("[DISC] Port: %d  Radio-Ports: %d  Antennen: %d  Mode: %s  Uptime: %lus",
         agTcpPort, agPorts, agAntennas, agModeStr, agUptime);
  agFound = true;
  udp.stop();
  ssePushStatus();
}

// ═══════════════════════════════════════════════════════════════════════════
//  TCP-Verbindung zum AG aufbauen
// ═══════════════════════════════════════════════════════════════════════════

void connectToAG() {
  if (millis() - agLastConnect < AG_RECONNECT_MS) return;
  agLastConnect = millis();

  static uint8_t failCount = 0;

  uint16_t port = (agTcpPort > 0) ? agTcpPort : AG_PORT;
  webLog("[AG] Verbinde mit %s:%d ...", agIPStr, port);
  snprintf(agStatusStr, sizeof(agStatusStr), "Verbinde...");

  if (!agClient.connect(agIP, port)) {
    failCount++;
    webLog("[AG] Verbindung fehlgeschlagen (Versuch %d)", failCount);
    snprintf(agStatusStr, sizeof(agStatusStr), "Fehler");
    // Nach 5 fehlgeschlagenen Versuchen AG neu suchen
    if (failCount >= 5) {
      webLog("[AG] Zu viele Fehler – suche AG neu via Broadcast");
      failCount  = 0;
      agFound    = false;
      agConnected = false;
    }
    return;
  }

  failCount = 0;
  agClient.setNoDelay(true);
  agConnected  = false;
  agConfigDone = false;
  agCfgState   = AGCFG_IDLE;
  agLineBuf    = "";
  agSeq        = 1;
  lastPing     = millis();

  webLog("[AG] TCP verbunden, warte auf Prologue...");
  snprintf(agStatusStr, sizeof(agStatusStr), "Prologue...");
  agConnected = true;
}

// ═══════════════════════════════════════════════════════════════════════════
//  AG nicht-blockierender Empfang
// ═══════════════════════════════════════════════════════════════════════════

void handleAGReceive() {
  if (!agClient.connected()) {
    webLog("[AG] Verbindung getrennt");
    agClient.stop();
    agConnected  = false;
    agConfigDone = false;
    agCfgState   = AGCFG_IDLE;
    snprintf(agStatusStr, sizeof(agStatusStr), "Getrennt");
    ssePushStatus();
    return;
  }

  // Daten lesen – solange etwas verfügbar ist
  bool gotData = false;
  while (agClient.available()) {
    gotData = true;
    char c = agClient.read();
    if (c == '\r') continue;
    if (c != '\n') { agLineBuf += c; continue; }
    String line = agLineBuf;
    agLineBuf = "";
    if (line.length() == 0) continue;
    agProcessLine(line);
  }

  // Verzögerter Config-Start nach Prologue (ersetzt delay(200), nicht-blockierend)
  if (agConfigStartAt > 0 && millis() >= agConfigStartAt) {
    agConfigStartAt = 0;
    agStartConfig();
    return;
  }

  // Timeout nur prüfen wenn KEINE Daten kamen und wir auf eine Antwort warten.
  // Timeout-Uhr läuft erst ab dem Moment wo das Kommando gesendet wurde
  // (wird in agStartConfig/agHandleConfigResponse gesetzt).
  if (!gotData &&
      agCfgState != AGCFG_IDLE && agCfgState != AGCFG_DONE &&
      agCfgTimeout > 0 && millis() > agCfgTimeout) {

    webLog("[AG] TIMEOUT Config-Schritt %d – ueberspringe", (int)agCfgState);
    agCfgTimeout = 0;  // Einmalig auslösen, nicht wiederholen

    switch (agCfgState) {
      case AGCFG_WAIT_SUB_PORT:
        webLog("[AG] Ueberspringe sub port – starte band list");
        agCfgState   = AGCFG_WAIT_BAND_LIST;
        sendAGCfgCmd("band list");
        break;
      case AGCFG_WAIT_BAND_LIST:
        webLog("[AG] Ueberspringe band list – starte antenna list");
        agCfgState   = AGCFG_WAIT_ANTENNA_LIST;
        sendAGCfgCmd("antenna list");
        break;
      case AGCFG_WAIT_ANTENNA_LIST:
        webLog("[AG] Ueberspringe antenna list – Config abgeschlossen");
        agCfgState   = AGCFG_DONE;
        agConfigDone = true;
        snprintf(agStatusStr, sizeof(agStatusStr), "OK (unvollst.)");
        ssePushStatus();
        break;
      default:
        agCfgState = AGCFG_DONE;
        break;
    }
  }
}

// ─── Einzelne AG-Zeile verarbeiten ────────────────────────────────────────

void agProcessLine(const String &line) {
  // Prologue: "V4.0.22 AG" — kommt direkt nach Connect
  if (line.startsWith("V") && line.indexOf(" AG") > 0) {
    char fw[16] = {0};
    sscanf(line.c_str() + 1, "%15s", fw);
    snprintf(agFwStr, sizeof(agFwStr), "%s", fw);
    webLog("[AG] Prologue: %s", line.c_str());
    // 200 ms Pause NICHT blockierend: agConfigStartAt setzen,
    // handleAGReceive() prüft diesen Timer in jedem Loop-Durchlauf
    agConfigStartAt = millis() + 200;
    return;
  }

  // Status-Nachricht: S0|<message>
  if (line.startsWith("S0|")) {
    webLog("[AG] Status: %s", line.c_str());
    agHandleStatusMessage(line);
    return;
  }

  // Antwort auf ein Kommando: R<seq>|<hex>|<message>
  if (line.startsWith("R")) {
    agHandleConfigResponse(line);
    return;
  }

  webLog("[AG] ?: %s", line.c_str());
}

// ─── Konfigurationssequenz starten ────────────────────────────────────────
// Reihenfolge laut Protokoll-Doku:
//  1. sub port all → Port-Statusänderungen abonnieren (Parameter "all" Pflicht!)
//     sub antenna existiert NICHT – nur: antenna, group, output, port, relay
//  2. band list    → Bänder einlesen
//  3. antenna list → Antennen einlesen
//  Port-Status kommt automatisch als S0|port nach sub port all.

void agStartConfig() {
  webLog("[AG] Starte Konfigurationssequenz...");
  snprintf(agStatusStr, sizeof(agStatusStr), "Konfiguriere");
  bandCount    = 0;
  antennaCount = 0;
  memset(bands,    0, sizeof(bands));
  memset(antennas, 0, sizeof(antennas));
  agCfgState   = AGCFG_WAIT_SUB_PORT;
  sendAGCfgCmd("sub port all");
}

// ─── Config-Antworten verarbeiten (nicht-blockierend) ─────────────────────
// Das AG-Protokoll: jeder Antwortblock endet mit einer Zeile R<seq>|0|
// (leere Message-Teil). Mehrzeilige Antworten (band list etc.) haben
// mehrere R<seq>|0|<daten> Zeilen und enden mit R<seq>|0| (leer).
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
